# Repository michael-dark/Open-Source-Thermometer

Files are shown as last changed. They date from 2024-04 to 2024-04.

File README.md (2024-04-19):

# Open-Source-Thermometer
This project is to develop an open-source hardware and software solution for an internet-connected thermometer. Specifically, this is designed to log data to an SD card as well as send to an InfluxDB database (https://www.influxdata.com). This supports up to four thermocouples, as well as measuring room temperature and relative humidity. 

## Hardware
* Processor - [Adafruit Metro S3](https://www.adafruit.com/product/5500)
* Display - [Adafruit Monochrome 1.12" 128x128 OLED Graphic Display - STEMMA QT / Qwiic](https://www.adafruit.com/product/5297)
* Thermocouple sensor(s) - [Adafruit MCP9601 (MCP96L01) I2C Thermocouple Amplifier - STEMMA QT / Qwiic](https://www.adafruit.com/product/5165)
* Room Temp / Humidity Sensor - [Adafruit Sensirion SHT40 Temperature & Humidity Sensor - STEMMA QT / Qwiic](https://www.adafruit.com/product/4885)
* (optional) Battery - Any 3.7V lithium ion battery with a JST connector - i.e. [this](https://www.adafruit.com/product/2011)
* K-type thermocouple (unless code is changed for other thermocouples) - i.e. (this)[https://www.adafruit.com/product/3245]
* M2.5 socket-head screws and nuts (6 each)
* M3 50mm socket-head screws and M3 nuts (4 each)
* M3 socket-head screws and nuts (variable depending on sensors installed)

**NOTE:** The only soldering potentially needed for this project is to set the address if more than one thermocouple per thermometer is desired. (See [this page](https://learn.adafruit.com/adafruit-mcp9600-i2c-thermocouple-amplifier/pinouts) for more information on setting addresses.) By default, the thermocouple sensor is set to the address 0x67, which is coded as thermocouple 1. 

The code sets the thermocouple numbers based on the address:
|Address|Thermocouple number|
|:---:|:---:|
|0x67|1|
|0x66|2|
|0x65|3|
|0x64|4|

However, this can be changed in the source code. 

## Case
STEP and STL files for the components of the case are included. **NOTE:** STLs may need to be rotated to print correctly. I did not need supports to print these, but that may vary depending on the 3D printer and plastic used.

## Firmware
The UF2 file can be uploaded via the Adafruit Bootloader (see instructions [here](https://learn.adafruit.com/adafruit-feather-m0-express-designed-for-circuit-python-circuitpython/uf2-bootloader-details), albeit for a different board). Press the reset button (next to the USB C connector) twice to enter bootloader mode. A new drive called "METROS3BOOT" should appear. Copy the THERMO.UF2 file to the METROS3BOOT drive, and it should load the firmware and reboot.

Alternatively, you can download the .INO Arduino file, load the libraries indicated in the #include statements, and compile the source and send it to the Metro via the [Arduino IDE](https://www.arduino.cc/en/software).

## Power
The device can be powered from the USB C power or via 6-12V power supply to the barrel jack. It requires a 5.5mm/2.1mm center-positive DC connector.

## Thermocouple
Any K-type thermocouple can be used as is. If other thermocouples are used, the thermocouple type in the code must be changed to reflect the thermocouple installed.

## Config file
The configuration file must be named thermo.cfg and be on the SD card. It is a plain text file. All lines start with the parameter, followed by an equal sign, then the parameter. In the included sample thermo.cfg, delete everything to the right of the = on each line. 

|Parameter|Legal Values|Explanation|
|---|---|---|
|WPA2Ent|0 or 1| Use WPA2 Enterprise? 0 - off, 1 - on|
|SSID||SSID of your WiFi network|
|Ident||Username for WPA2 Enterprise|
|PW||Password for WiFi|
|USECERT|0 or 1|Use certificate file for WPA2 Enterprise? 0 - no, 1 - yes|
|CERTFILE||Certificate file name|
|INFLUXDB_URL|(url beginning with http/https)|InfluxDB URL (from InfluxDB website)|
|INFLUXDB_TOKEN||InfluxDB Token (from InfluxDB website)|
|INFLUXDB_ORG||InfluxDB Org (from InfluxDB website)|
|INFLUXDB_BUCKET||InfluxDB Bucket (from InfluxDB website)|
|TZ_INFO|POSIX timezone|Current POSIX Timezone (see [here](https://support.cyberdata.net/portal/en/kb/articles/010d63c0cfce3676151e1f2d5442e311) for list|
|TC1_ENABLE|0 or 1|Enable first thermocouple (1 - yes, 0 - no)|
|TC2_ENABLE|0 or 1|Enable second thermocouple (1 - yes, 0 - no)|
|TC3_ENABLE|0 or 1|Enable third thermocouple (1 - yes, 0 - no)|
|TC4_ENABLE|0 or 1|Enable fourth thermocouple (1 - yes, 0 - no)|
|RT_ENABLE|0 or 1|Enable room temp measurement (1 - yes, 0 - no)|
|ROOM||Room device is in|
|TC1_DEVICE||First thermocouple device|
|TC1_SERVICE||First thermocouple service|
|TC2_DEVICE||Second thermocouple device|
|TC2_SERVICE||Second thermocouple service|
|TC3_DEVICE||Third thermocouple device|
|TC3_SERVICE||Third thermocouple service|
|TC4_DEVICE||Fourth thermocouple device|
|TC4_SERVICE||Fourth thermocouple service|
|TC1_OFFSET||First thermocouple offset (in degrees C)|
|TC2_OFFSET||Second thermocouple offset (in degrees C)|
|TC3_OFFSET||Third thermocouple offset (in degrees C)|
|TC4_OFFSET||Fourth thermocouple offset (in degrees C)|
|RT_OFFSET||Room temperature offset (in degrees C)|
|RH_OFFSET||Humidity offset (in degrees C)|
|FREQUENCY|<Integer>|Logging frequency (in minutes)|
|LOG_TO_SD|0 or 1|Save temps to SD card? (1 - yes, 0 - no)|

## InfluxDB Setup
I created a free account on [InfluxDB](https://www.influxdata.com) - however, you could run a local instance as well. See the InfluxDB documentation for setup. I then used [Grafana](https://grafana.com) for visualization.

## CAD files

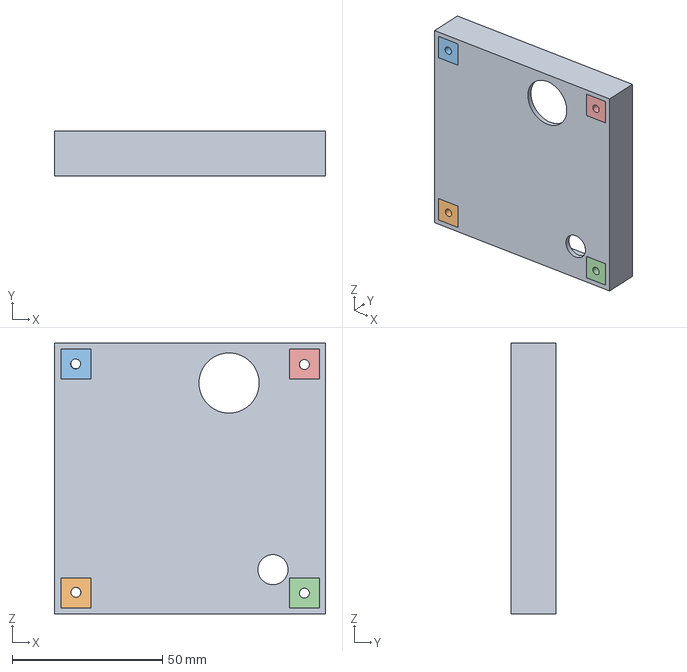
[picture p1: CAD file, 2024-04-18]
3D Files/Battery Box.step
90.1 x 15.0 x 90.0 mm

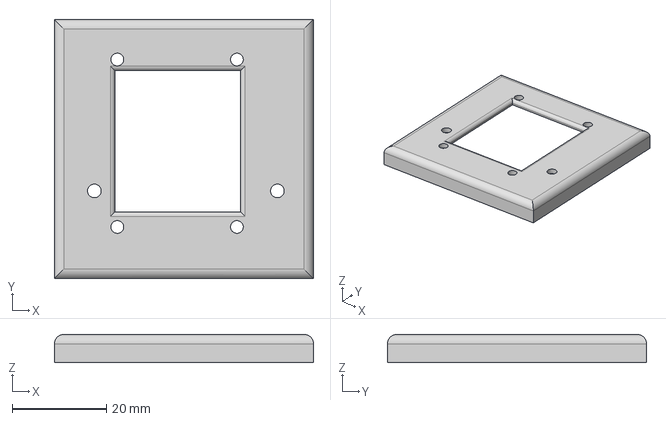
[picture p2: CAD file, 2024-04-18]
3D Files/OLED Holder.step
55.0 x 55.0 x 6.00 mm

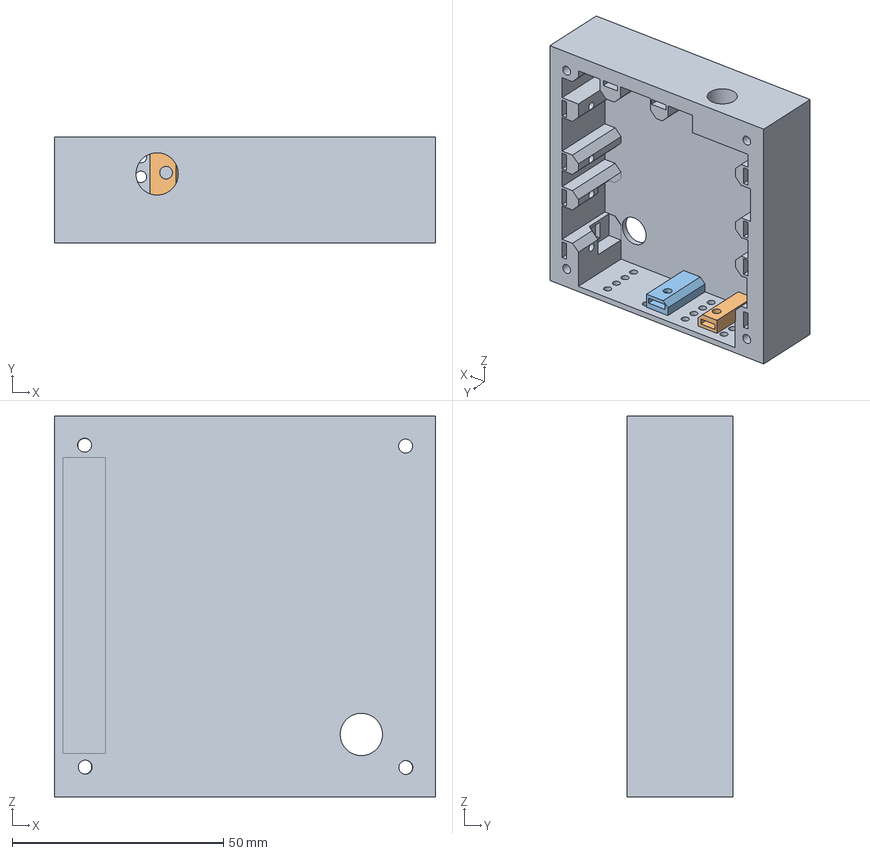
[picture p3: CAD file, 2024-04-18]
3D Files/SensorBox.step
90.1 x 25.0 x 90.0 mm

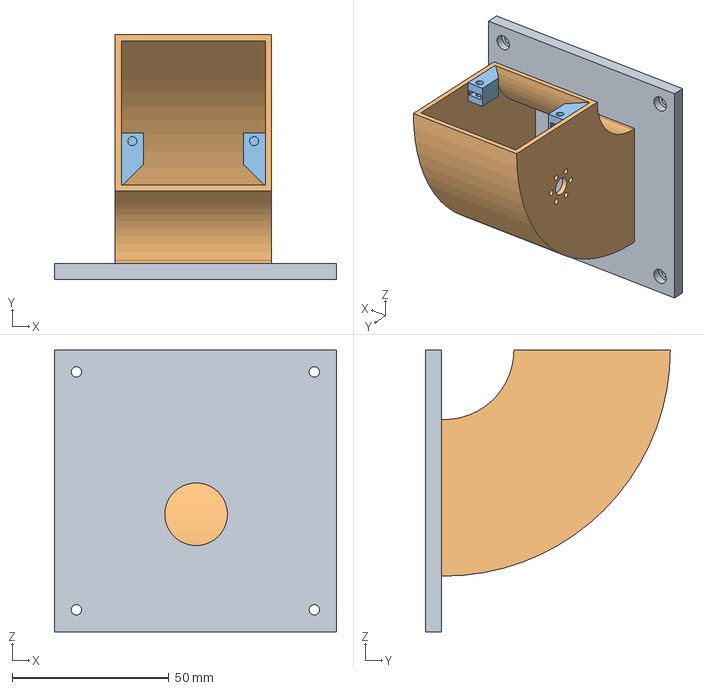
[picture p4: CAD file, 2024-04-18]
3D Files/Lid.step
90.1 x 78.2 x 90.0 mm

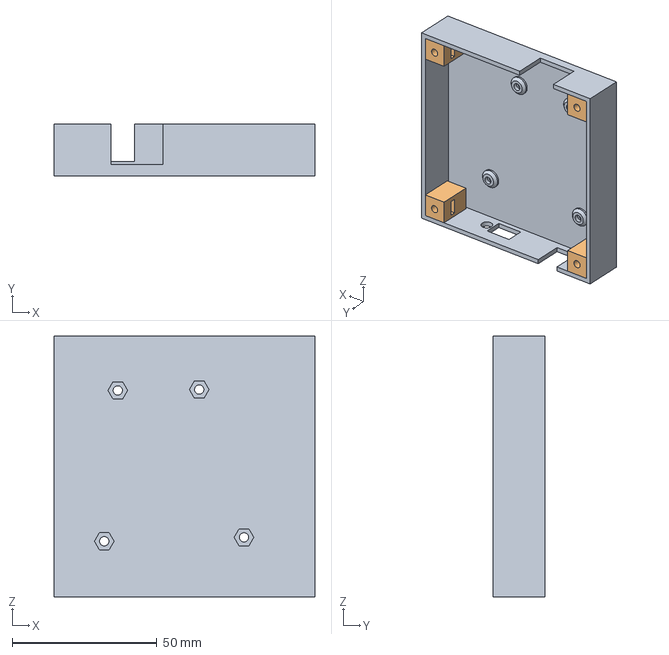
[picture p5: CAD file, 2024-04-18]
3D Files/Compute box.step
90.0 x 18.0 x 90.0 mm

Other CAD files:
3D Files/Battery Box.stl
3D Files/Compute box.stl
3D Files/Lid.stl
3D Files/OLED Holder.stl
3D Files/SensorBox.stl

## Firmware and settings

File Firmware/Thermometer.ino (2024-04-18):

#include <SPI.h>
#include <Wire.h>
#include <Adafruit_GFX.h>
#include <Adafruit_SH110X.h>
#include "Adafruit_SHT4x.h"
#include "SdFat.h"
#include "Adafruit_MCP9601.h"
#include "RTClib.h"
#include <WiFi.h>
#include "esp_eap_client.h"  //wpa2 library for connections to Enterprise networks
#include "time.h"
#include <InfluxDbClient.h>
#include <InfluxDbCloud.h>

#define DEVICE "OpenSourceVetV1" // Device name
#define MAXNUMTC 4 // Maximum number of thermocouples
#define WIFI_TIMEOUT 1 // Try to connect for 1 minute
#define FILE_NAME "thermo.cfg" // Config file name

#define KEY_MAX_LENGTH 30     // change it if key is longer
#define VALUE_MAX_LENGTH 140  // change it if value is longer

// variables for Config file
int WPA2Ent = 0;
int RT_ENABLE = 1;
int USECERT = 0;
int TC[MAXNUMTC] = { 0 };
float TC_OFFSET[MAXNUMTC] = { 0 };
float RT_OFFSET = 0;
float RH_OFFSET = 0;
int FREQUENCY = 5;
String SSID;
String Ident;
String PW;
String INFLUXDB_URL;
String INFLUXDB_TOKEN;
String INFLUXDB_ORG;
String INFLUXDB_BUCKET;
String TZ_INFO = "UTC";
String ROOM;
String TC_DEVICE[MAXNUMTC] = { "" };
String TC_SERVICE[MAXNUMTC] = { "" };
String CERTFILE;
unsigned long logMillis;
unsigned long timeSyncMillis;
int LOG_TO_SD = 0;
bool bufEmpty = true;

int ident_count[MAXNUMTC] = { 0 };
float prev_temp[MAXNUMTC] = { 0 };

InfluxDBClient client;
// Declare Data point

int TC_ADDR[MAXNUMTC] = { 0x67, 0x66, 0x65, 0x64 };
#define SD_FAT_TYPE 3
#define SD_CS_PIN SS
#define SCREEN_WIDTH 128   // OLED display width, in pixels
#define SCREEN_HEIGHT 128  // OLED display height, in pixels
#define OLED_RESET -1      // can set an oled reset pin if desired

Adafruit_SH1107 display = Adafruit_SH1107(SCREEN_WIDTH, SCREEN_HEIGHT, &Wire, OLED_RESET, 1000000, 100000);

SdFat SD;
File logFile;
File errFile;
Adafruit_SHT4x sht4 = Adafruit_SHT4x();
Adafruit_MCP9601 mcp[4];
RTC_PCF8523 rtc;
int RT = 1;

void setup() {

  SSID.reserve(140);
  Ident.reserve(140);
  PW.reserve(140);
  INFLUXDB_URL.reserve(140);
  INFLUXDB_TOKEN.reserve(140);
  INFLUXDB_ORG.reserve(140);
  INFLUXDB_BUCKET.reserve(140);
  TZ_INFO.reserve(140);
  ROOM.reserve(140);
  CERTFILE.reserve(140);

  bool goodWiFi = 0;

  logMillis = 0;
  timeSyncMillis = 0;

  for (int i = 0; i < MAXNUMTC; i++) {
    TC[i] = 0;
  }

  Serial.begin(9600);
  delay(500);

  display.begin(0x3D, true);  // Address 0x3D default
  display.cp437(true);
  display.setTextColor(SH110X_WHITE);
  display.clearDisplay();
  display.setTextSize(2);  // Draw 2X-scale text
  display.println("Starting Temp!");
  display.setTextSize(1);  // Draw 2X-scale text
  display.println(WiFi.macAddress());
  Serial.println(WiFi.macAddress());
  display.setTextSize(2);
  display.display();

  if (!SD.begin(SD_CS_PIN)) {
    display.setTextSize(2);  // Draw 2X-scale text
    display.setTextColor(SH110X_WHITE);
    display.println(F("SD Card"));
    display.println(F("Fail - "));
    display.println(F("Chk Card!"));
    display.display();
    while (1) delay(10);
  }

  display.setTextSize(1);
  display.println("Initialized SD card");
  display.setTextSize(2);
  display.display();

  getConfigValues();

  display.setTextSize(1);
  display.println("Read config values");
  display.display();
  display.setTextSize(2);

  Serial.println(WPA2Ent);
  Serial.println(SSID);
  Serial.println(Ident);
  Serial.println(PW);
  Serial.println(INFLUXDB_URL);
  Serial.println(INFLUXDB_TOKEN);
  Serial.println(INFLUXDB_ORG);
  Serial.println(INFLUXDB_BUCKET);
  Serial.println(TZ_INFO);
  Serial.println(ROOM);
  Serial.println(FREQUENCY);
  Serial.println(USECERT);
  Serial.println(CERTFILE);

  for (int i = 0; i < MAXNUMTC; i++) {
    char ichar[10];
    itoa((i + 1), ichar, 10);
    if (TC[i]) {
      if (!mcp[i].begin(TC_ADDR[i])) {
        Serial.print("Failed to intialize thermocouple #");
        Serial.println(i);
        TC[i] = 0;
      } else {
        mcp[i].setADCresolution(MCP9600_ADCRESOLUTION_16);
        mcp[i].setThermocoupleType(MCP9600_TYPE_K);
        mcp[i].setFilterCoefficient(3);

        char buf[200];
        strcpy(buf, "TC");
        strcat(buf, ichar);
        strcat(buf, " Device");
        //free(buf);
        strcpy(buf, "TC");
        strcat(buf, ichar);
        strcat(buf, " Service");
        //      free(buf);
        //      free(ichar);
      }
    }
  }

  display.setTextSize(1);
  display.println("Init ");
  display.println("thermocpls");
  display.setTextSize(2);
  display.display();

  if (!RT_ENABLE) {
    RT = 0;
  }
  else if (!sht4.begin()) {
    RT = 0;
  } else {
    sht4.setPrecision(SHT4X_HIGH_PRECISION);
    sht4.setHeater(SHT4X_NO_HEATER);
  }

  if (!RT) {
    display.setTextSize(1);
    display.println("Skipped room temp");
    display.setTextSize(2);
    display.display();
  }
  else {
    display.setTextSize(1);
    display.println("Initialized room temp");
    display.setTextSize(2);
    display.display();
  }
    display.setTextSize(1);
    display.print("Init WiFi (");
    display.print(WIFI_TIMEOUT);
      display.println("min max)");
    display.setTextSize(2);
    display.display();

  goodWiFi = connectWiFi();

  if (goodWiFi) {
    display.setTextSize(1);
    display.println("Initialized WiFi");
    display.setTextSize(2);
    display.display();
  }
  else {
    display.setTextSize(1);
    display.println("WiFi init fail");
    display.setTextSize(2);
    display.display();
  }
  if (!rtc.begin()) {
    display.setTextSize(2);  // Draw 2X-scale text
    display.setTextColor(SH110X_WHITE);
    display.println(F("RTC Fail"));
    display.display();
    while (1) delay(10);
  }

  display.setTextSize(1);
  display.println("Initialized RTC");
  display.setTextSize(2);
  display.display();

  if(goodWiFi) {
    initTime(TZ_INFO);
  }
  DateTime now = rtc.now();

  char filename[50];
  snprintf(filename, 50, "%d-%d-%d_%d-%d-%d.csv", now.year(), now.month(), now.day(), now.hour(), now.minute(), now.second());

  delay(100);

  errFile = SD.open("Error.txt", FILE_WRITE);

  logFile = SD.open(filename, FILE_WRITE);
  if (!logFile) {
    display.setTextSize(2);  // Draw 2X-scale text
    display.setTextColor(SH110X_WHITE);
    display.println(F("Logfile Fail"));
    display.display();
    while (1) delay(10);
  }
  logFile.print("Date, Time, Room Temp, Rel Hum");
  for (int i = 0; i < MAXNUMTC; i++) {
    char ichar[10];
    itoa((i + 1), ichar, 10);
    if (TC[i]) {
      char buf[200];
      strcpy(buf, ", TC");
      strcat(buf, ichar);
      strcat(buf, ", TC");
      strcat(buf, ichar);
      strcat(buf, " status");
      logFile.print(buf);
      //      free(buf);
    }
    //    free(ichar);
  }
  logFile.println();

  display.setTextSize(1);
  display.println("Initialized log file");
  display.setTextSize(2);
  display.display();

  Serial.println("End of Setup!");
}

void displayTime() {
  DateTime now = rtc.now();

  char timeFormat[] = "hh:mm:ss";
  char *time = now.toString(timeFormat);
  char dateBuf[20];
  sprintf(dateBuf, "%02d/%02d/%02d", now.month(), now.day(), now.year());

  display.setTextSize(2);
  //  display.println(F(dateBuf));
  display.setTextSize(2);
  display.print(" ");
  display.println(time);
  display.setTextSize(1);
  display.println("--------------------");
  display.setTextSize(2);
}

void displayTemp() {

  float TCTemp;
  for (int i = 0; i < MAXNUMTC; i++) {
    char ichar[10];
    itoa((i + 1), ichar, 10);
    if (TC[i]) {
      char buf[200];
      strcpy(buf, ichar);
      strcat(buf, ":");

      strcat(buf, getTCTemp(i).c_str());
      display.print(buf);
      display.write(0xF8);
      display.println(F("C"));
    } else {
      display.println();
    }
  }

  display.setTextSize(1);
  display.println("--------------------");
  display.setTextSize(2);
}

void loop() {

  Serial.println("Loop function!");
  unsigned long logMillis = 0;
  unsigned long timeSyncMillis = 0;
  while (1) {

    if (millis() - timeSyncMillis >= (60 * 60 * 1000UL)) {
      timeSyncMillis = millis();  //get ready for the next iteration
      Serial.println("Going to sync...");
      initTime(TZ_INFO);
    }

    if ((millis() - logMillis) >= (FREQUENCY * 60 * 1000UL)) {
      logMillis = millis();  //get ready for the next iteration
      Serial.println("Going to log...");

      bufEmpty = logValues();
      WiFi.disconnect(true);
    }

    display.clearDisplay();
    display.setCursor(0, 0);

    displayTime();
    displayTemp();

    if (RT) {
      display.setTextSize(1);
      display.print(F("RT:"));
      display.printf(getRT().c_str());
      display.write(0xF8);
      display.print(F("C | "));
      display.print(F("RH:"));
      display.printf(getRH().c_str());
      display.println(F("%"));

      if (bufEmpty) {
        display.println(" Buffer Empty  ");

      } else {
        display.println(" Data Buffered ");
      }

      display.println(WiFi.macAddress());

      display.setTextSize(2);
    }
    display.display();
    delay(150);
  }
}

String getTCTemp(int i) {
  if (TC[i]) {
    char ichar[10];
    itoa((i + 1), ichar, 10);
/*    uint8_t status = mcp[i].getStatus();
          if (status & MCP9601_STATUS_OPENCIRCUIT) {
            return "Open";
          } else if (status & MCP9601_STATUS_SHORTCIRCUIT) {
            return "Short";
          } else
            if (TC[i]) {
*/
    char buf[200];
    float TCTemp;
    TCTemp = mcp[i].readThermocouple();
    Serial.print("TC");
    Serial.print(i);
    Serial.print(" Status:");
    Serial.println(mcp[i].getStatus());
    Serial.print("Cur Temp:");
    Serial.println(TCTemp);
    Serial.print("Prev Temp:");
    Serial.println(prev_temp[i]);
    if (TCTemp == prev_temp[i]) {
      ident_count[i]++;
      if(ident_count[i] > 500) {
//        ESP.restart();
      Serial.println("500 identical temp readings");
      }
    }
    else {
      prev_temp[i] = TCTemp;
      ident_count[i] = 0;
    }
    
    TCTemp = TCTemp - TC_OFFSET[i];
            char TCbuf[15];
            dtostrf(TCTemp, 0, 2, TCbuf);
    return String(TCTemp, 1);
//          }
  }
}

String getRT(void) {
  char tempBuf[15];
  sensors_event_t humidity, temp;
  sht4.getEvent(&humidity, &temp);  // populate temp and humidity objects with fresh data
                                    // dtostrf((temp.temperature-RT_OFFSET), 0, 2, tempBuf);
  return String((temp.temperature - RT_OFFSET), 1);
}

String getRH(void) {
  char humBuf[15];
  sensors_event_t humidity, temp;
  sht4.getEvent(&humidity, &temp);  // populate temp and humidity objects with fresh data
                                    //  dtostrf((humidity.relative_humidity-RH_OFFSET), 0, 2, humBuf);
  return String((humidity.relative_humidity - RH_OFFSET), 1);
}

bool logValues( void ) {

  Serial.println("logValues function");

  if (WiFi.status() != WL_CONNECTED) {
    bool goodWiFi = connectWiFi();
  }

  DateTime now = rtc.now();

  char timeFormat[] = "hh:mm:ss";
  char *time = now.toString(timeFormat);
  char dateBuf[20];
  sprintf(dateBuf, "%02d/%02d/%02d", now.month(), now.day(), now.year());

  InfluxDBClient client(INFLUXDB_URL, INFLUXDB_ORG, INFLUXDB_BUCKET, INFLUXDB_TOKEN, InfluxDbCloud2CACert);
  if (client.validateConnection()) {
    Serial.print("Connected to InfluxDB: ");
    Serial.println(client.getServerUrl());

    errFile.print(dateBuf);
    errFile.print(" - ");
    errFile.print(time);
    errFile.print(":");
    errFile.println("Connected to InfluxDB");

  } else {
    Serial.print("InfluxDB connection failed: ");
    Serial.println(client.getLastErrorMessage());
    errFile.print(dateBuf);
    errFile.print(" - ");
    errFile.print(time);
    errFile.print(":");
    errFile.println("InfluxDB connect failed!");
    errFile.println(client.getLastErrorMessage());
  }

  Point sensor("Lab_Monitoring");
    Serial.print("Point 1");

  client.setWriteOptions(WriteOptions().batchSize(1));
  client.setWriteOptions(WriteOptions().bufferSize(100));
    Serial.print("Point 2");

  sensor.clearTags();
    Serial.print("Point 3");

  sensor.addTag("device", DEVICE);
  sensor.addTag("SSID", WiFi.SSID());
  sensor.addTag("MAC Address", WiFi.macAddress());
  sensor.addTag("Room", ROOM);

      Serial.print("Point 4");

  sensor.addField(ROOM + " Room Temp", getRT().toFloat());
  sensor.addField(ROOM + " Relative Humidity", getRH().toFloat());
  sensor.addField(ROOM + " WiFi Signal Strength", WiFi.RSSI());
      Serial.print("Point 5");

//  if (!client.writePoint(sensor)) {
//    Serial.print("InfluxDB write 1 failed: ");
//    Serial.println(client.getLastErrorMessage());
//  }

//  sensor.clearFields();

  String TCLogTemps[MAXNUMTC];
  String TCStatus[MAXNUMTC];
    Serial.print("Point 6");

  for (int i = 0; i < MAXNUMTC; i++) {

    if (TC[i]) {
    Serial.print("Point 7");
    Serial.print(i);

      sensor.addTag(TC_DEVICE[i] + " Service", TC_SERVICE[i]);
    Serial.print("Point 7a");
      sensor.addField(TC_DEVICE[i] + " Temp", getTCTemp(i).toFloat());
    Serial.print("Point 7b");
      TCLogTemps[i] = getTCTemp(i).toFloat();
    Serial.print("Point 7c");
      TCStatus[i] = mcp[i].getStatus();
    Serial.print("Point 7d");
    }
  }
    Serial.print("Point 8");
  if (!client.writePoint(sensor)) {
    Serial.print("InfluxDB write 2 failed: ");
    Serial.println(client.getLastErrorMessage());

    errFile.print(dateBuf);
    errFile.print(" - ");
    errFile.print(time);
    errFile.print(":");
    errFile.println("InfluxDB write failed!");
    errFile.println(client.getLastErrorMessage());

  }
  sensor.clearFields();

  char logLine[300];
  char logLine2[200];
  char logLine3[200];
  sprintf(logLine, "%s,%s,%.1f,%.1f,", dateBuf, time, getRT().toFloat(), getRH().toFloat());
  Serial.println(logLine);
  sprintf(logLine2, "%s,", TCLogTemps);
  Serial.println(logLine2);
  sprintf(logLine3, "%s,", TCStatus);
  Serial.println(logLine3);
//  logLine2[strlen(logLine2) - 1] = '\0';
  logLine3[strlen(logLine3) - 1] = '\0';
  strcat(logLine, logLine2);
  strcat(logLine, logLine3);
  Serial.println("logLine strcat");
  logFile.println(logLine);
  logFile.flush();

  return client.isBufferEmpty();
}


/*
 * This Arduino Nano code was developed by newbiely.com
 *
 * This Arduino Nano code is made available for public use without any restriction
 *
 * For comprehensive instructions and wiring diagrams, please visit:
 * https://newbiely.com/tutorials/arduino-nano/arduino-nano-read-config-from-sd-card
 */

bool SD_available(const __FlashStringHelper *key) {
  char value_string[VALUE_MAX_LENGTH];
  int value_length = SD_findKey(key, value_string);
  return value_length > 0;
}

int SD_findInt(const __FlashStringHelper *key) {
  char value_string[VALUE_MAX_LENGTH];
  int value_length = SD_findKey(key, value_string);
  return HELPER_ascii2Int(value_string, value_length);
}

float SD_findFloat(const __FlashStringHelper *key) {
  char value_string[VALUE_MAX_LENGTH];
  int value_length = SD_findKey(key, value_string);
  return HELPER_ascii2Float(value_string, value_length);
}

String SD_findString(const __FlashStringHelper *key) {
  char value_string[VALUE_MAX_LENGTH];
  int value_length = SD_findKey(key, value_string);
  return HELPER_ascii2String(value_string, value_length);
}


int SD_findKey(const __FlashStringHelper *key, char *value) {
  File configFile = SD.open(FILE_NAME);

  if (!configFile) {
    Serial.print(F("SD Card: error on opening file "));
    Serial.println(FILE_NAME);
    return (0);
  }

  char key_string[KEY_MAX_LENGTH];
  char SD_buffer[KEY_MAX_LENGTH + VALUE_MAX_LENGTH + 1];  // 1 is = character
  int key_length = 0;
  int value_length = 0;

  // Flash string to string
  PGM_P keyPoiter;
  keyPoiter = reinterpret_cast<PGM_P>(key);
  byte ch;
  do {
    ch = pgm_read_byte(keyPoiter++);
    if (ch != 0)
      key_string[key_length++] = ch;
  } while (ch != 0);

  // check line by line
  while (configFile.available()) {
    int buffer_length = configFile.readBytesUntil('\n', SD_buffer, (KEY_MAX_LENGTH + VALUE_MAX_LENGTH + 1));
    if (SD_buffer[buffer_length - 1] == '\r')
      buffer_length--;  // trim the \r

    if (buffer_length > (key_length + 1)) {                  // 1 is = character
      if (memcmp(SD_buffer, key_string, key_length) == 0) {  // equal
        if (SD_buffer[key_length] == '=') {
          value_length = buffer_length - key_length - 1;
          memcpy(value, SD_buffer + key_length + 1, value_length);
          break;
        }
      }
    }
  }

  configFile.close();  // close the file
  return value_length;
}

int HELPER_ascii2Int(char *ascii, int length) {
  int sign = 1;
  int number = 0;

  for (int i = 0; i < length; i++) {
    char c = *(ascii + i);
    if (i == 0 && c == '-')
      sign = -1;
    else {
      if (c >= '0' && c <= '9')
        number = number * 10 + (c - '0');
    }
  }

  return number * sign;
}

float HELPER_ascii2Float(char *ascii, int length) {
  int sign = 1;
  int decimalPlace = 0;
  float number = 0;
  float decimal = 0;

  for (int i = 0; i < length; i++) {
    char c = *(ascii + i);
    if (i == 0 && c == '-')
      sign = -1;
    else {
      if (c == '.')
        decimalPlace = 1;
      else if (c >= '0' && c <= '9') {
        if (!decimalPlace)
          number = number * 10 + (c - '0');
        else {
          decimal += ((float)(c - '0') / pow(10.0, decimalPlace));
          decimalPlace++;
        }
      }
    }
  }

  return (number + decimal) * sign;
}

String HELPER_ascii2String(char *ascii, int length) {
  String str;
  str.reserve(length);
  str = "";

  for (int i = 0; i < length; i++) {
    char c = *(ascii + i);
    str += String(c);
  }

  return str;
}


String get_wifi_status(int status) {
  switch (status) {
    case WL_IDLE_STATUS:
      return "WL_IDLE_STATUS";
    case WL_SCAN_COMPLETED:
      return "WL_SCAN_COMPLETED";
    case WL_NO_SSID_AVAIL:
      return "WL_NO_SSID_AVAIL";
    case WL_CONNECT_FAILED:
      return "WL_CONNECT_FAILED";
    case WL_CONNECTION_LOST:
      return "WL_CONNECTION_LOST";
    case WL_CONNECTED:
      return "WL_CONNECTED";
    case WL_DISCONNECTED:
      return "WL_DISCONNECTED";
  }
}

void setTimezone(String timezone) {
  Serial.printf("  Setting Timezone to %s\n", timezone.c_str());
  setenv("TZ", timezone.c_str(), 1);  //  Now adjust the TZ.  Clock settings are adjusted to show the new local time
  tzset();
}

void initTime(String timezone) {
  struct tm timeinfo;

  if (WiFi.status() != WL_CONNECTED) {
    bool goodWiFi = connectWiFi();
  }

  Serial.println("Setting up time");
  configTime(0, 0, "pool.ntp.org");  // First connect to NTP server, with 0 TZ offset
  if (!getLocalTime(&timeinfo)) {
    Serial.println("  Failed to obtain time");
    return;
  }
  Serial.println("  Got the time from NTP");
  // Now we can set the real timezone
  setTimezone(TZ_INFO);
  time_t now;
  time(&now);
  localtime_r(&now, &timeinfo);

  Serial.println(&timeinfo);

  int yr;
  int mt;
  int dy;
  int hr;
  int mi;
  int se;

  yr = timeinfo.tm_year + 1900;
  mt = timeinfo.tm_mon + 1;
  dy = timeinfo.tm_mday;
  hr = timeinfo.tm_hour;
  mi = timeinfo.tm_min;
  se = timeinfo.tm_sec;

  rtc.adjust(DateTime(yr, mt, dy, hr, mi, se));
}

void getConfigValues(void) {

  // WPA2 Enterprise? 1 - yes, 0 - no
  WPA2Ent = SD_findInt(F("WPA2Ent"));

  // SSID to connect to
  SSID = SD_findString(F("SSID"));

  // Identity (for WPA2 Enterprise)
  Ident = SD_findString(F("Ident"));

  // PW - either for identity (WPA2 Ent) or for access point (WPA2)
  PW = SD_findString(F("PW"));

  // InfluxDB URL
  INFLUXDB_URL = SD_findString(F("INFLUXDB_URL"));

  // InfluxDB Access Token
  INFLUXDB_TOKEN = SD_findString(F("INFLUXDB_TOKEN"));

  // InfluxDB Org
  INFLUXDB_ORG = SD_findString(F("INFLUXDB_ORG"));

  // InfluxDB Bucket
  INFLUXDB_BUCKET = SD_findString(F("INFLUXDB_BUCKET"));

  // POSIX Timezone string (see https://github.com/nayarsystems/posix_tz_db/blob/master/zones.csv)
  TZ_INFO = SD_findString(F("TZ_INFO"));

  // Room the sensor is in
  ROOM = SD_findString(F("ROOM"));

  // Frequency to log values in minutes
  FREQUENCY = SD_findInt(F("FREQUENCY"));

  // Write out to SD card as well as InfluxDB? 1 = yes, 0 = no
  LOG_TO_SD = SD_findInt(F("LOG_TO_SD"));

  // Use certificate for WPA2 Enterprise?
  USECERT = SD_findInt(F("USECERT"));

  // Filename of certificate to use for WPA2 Enterprise
  CERTFILE = SD_findString(F("CERTFILE"));

  // Enable room temp?
  RT_ENABLE = SD_findInt(F("RT_ENABLE"));

  // Enable thermocouples 1-4? 1 = yes, 0 = no
  TC[0] = SD_findInt(F("TC1_ENABLE"));
  TC[1] = SD_findInt(F("TC2_ENABLE"));
  TC[2] = SD_findInt(F("TC3_ENABLE"));
  TC[3] = SD_findInt(F("TC4_ENABLE"));

  for (int i = 0; i < MAXNUMTC; i++) {

    char buf[200];
    char ichar[10];
    itoa((i + 1), ichar, 10);
    strcpy(buf, "TC");
    strcat(buf, ichar);
    strcat(buf, "_DEVICE");

    // Device being monitored by thermocouple

    TC_DEVICE[i] = SD_findString(F(buf));
    //free(buf);
    strcpy(buf, "TC");
    strcat(buf, ichar);
    strcat(buf, "_SERVICE");

    // Service owning device being monitored
    TC_SERVICE[i] = SD_findString(F(buf));
    //    free(buf);
    //    free(ichar);

    strcpy(buf, "TC");
    strcat(buf, ichar);
    strcat(buf, "_OFFSET");

    // Offset from temperature - used for compensation for thermocouple variance

    TC_OFFSET[i] = SD_findFloat(F(buf));
  }

  // Offset for room temperature - used to compensate for calibration
  RT_OFFSET = SD_findFloat(F("RT_OFFSET"));

  // Offset for humidity - used to compensate for calibration
  RH_OFFSET = SD_findFloat(F("RH_OFFSET"));
}
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

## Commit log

2024-04-18 Move Battery Box.step to 3D Files/Battery Box.step
    [Battery Box.step]
2024-04-18 Move Battery Box.stl to 3D files/Battery Box.stl
    [Battery Box.stl]
2024-04-18 Move Battery Box.stl to Battery Box.stl
    [Battery Box.stl]
2024-04-18 Rename Compute box.step to 3D Files/Compute box.step
    [Compute box.step]
2024-04-18 Rename Compute box.stl to 3D Files/Compute box.stl
    [Compute box.stl]
2024-04-18 Rename Lid.step to 3D Files/Lid.step
    [Lid.step]
2024-04-18 Rename Lid.stl to 3D Files/Lid.stl
    [Lid.stl]
2024-04-18 Rename OLED Holder.step to 3D Files/OLED Holder.step
    [OLED Holder.step]
2024-04-18 Rename OLED Holder.stl to 3D Files/OLED Holder.stl
    [OLED Holder.stl]
2024-04-18 Rename SensorBox.step to 3D Files/SensorBox.step
    [SensorBox.step]
2024-04-18 Rename SensorBox.stl to 3D Files/SensorBox.stl
    [SensorBox.stl]
